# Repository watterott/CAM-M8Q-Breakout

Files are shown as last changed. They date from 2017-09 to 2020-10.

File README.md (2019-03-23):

# CAM-M8Q-Breakout
Breakout with u-blox CAM-M8Q Multi GNSS Module.

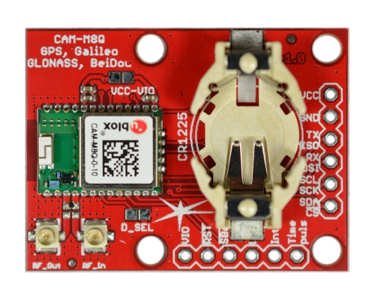
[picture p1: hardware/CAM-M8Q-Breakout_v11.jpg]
CAM-M8Q-Breakout


* [u-blox CAM-M8Q](https://www.u-blox.com/de/product/cam-m8-series) Multi GNSS Module
* GNSS Systems: GPS/QZSS, Galileo, GLONASS, BeiDou
* Interfaces: UART (default 9600 8N1), I2C/TWI (address 0x42), SPI
* on-board Antenna and optional external Antenna (u.Fl)
* 2.7 - 3.6V Power Supply
* Open-Source and released under the [Creative Commons Attribution Share-Alike License](https://creativecommons.org/licenses/by-sa/4.0/).
* **[Documentation on learn.watterott.com](https://learn.watterott.com)**

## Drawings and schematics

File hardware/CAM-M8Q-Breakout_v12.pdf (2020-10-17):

A

A

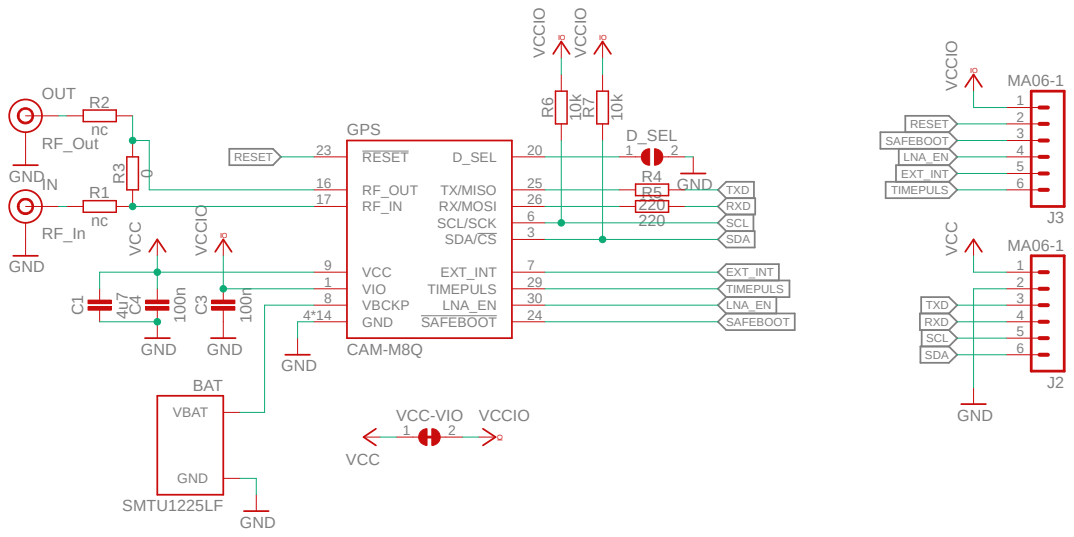
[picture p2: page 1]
GND ¹⁰⁰n; 100n VCC; GND; SMTU1225LF; MA06-1 VCCIO; VCC; VCCIO ⁴u7; ncnc; 0 RF_Out; VCCIO; 220 ¹⁰k; 10k VCCIO; Designed by Watterott electronic C⁴; VBAT; BAT; D_SEL; VCC 9 VIO 1; GND 4*14; VBCKP 8; RF_OUT 16 RF_IN 17; RESET 23; SAFEBOOT; 24 LNA_EN; EXT_INT; TX/MISO; RX/MOSI; TIMEPULS; SCL/SCK; SDA/CS; GPS; CAM-M8Q; OUT; WEEE; RoHS; RESET; LNA_EN; TXD; RXD; SCL; SDA; OSHW; Watterott

VCC-VIO C¹

Released under the Creative Commons Attribution Share-Alike
License. http://creativecommons.org/licenses/by-sa/4.0/

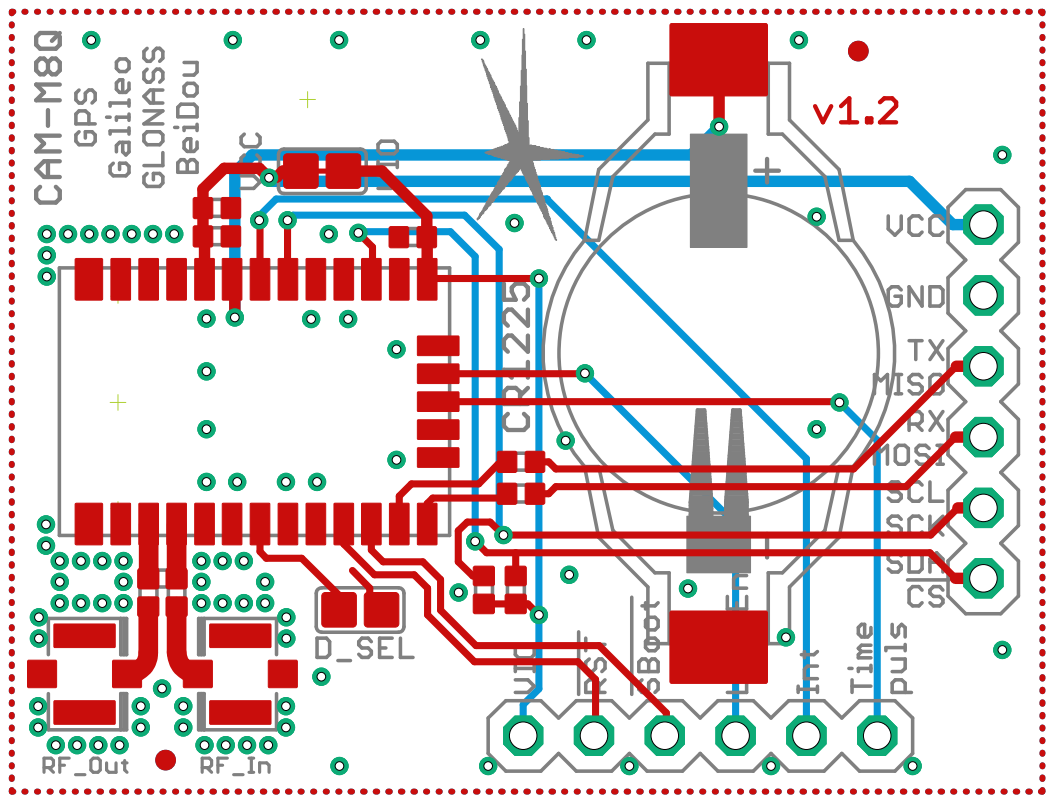
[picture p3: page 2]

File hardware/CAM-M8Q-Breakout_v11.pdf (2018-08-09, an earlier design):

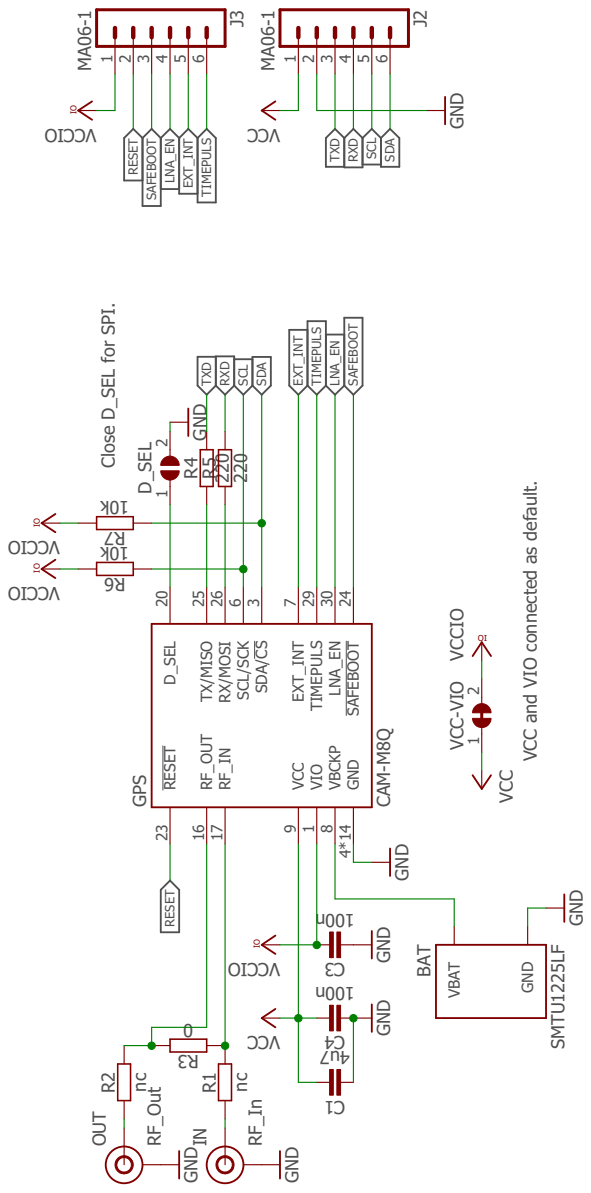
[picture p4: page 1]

Close D_SEL for SPI. VCC and VIO connected as default. GND n001 n001 CCV GND SMTU1225LF GND GND MA06-1 MA06-1 OI CCV VCC VCCIO 7u4 CCV GND GND ncnc 0 RF_Out RF_In GND GND OI CCV 220 220 k01 k01 OI CCV OI CCV Released under the Creative Commons Attribution Share-Alike License. http://creativecommons.org/licenses/by-sa/4.0/ Designed by Watterott electronic 3C4C BAT GND VBAT D_SEL2 1 J2 123456 J3 123456 VCC-VIO2 1 1C VCC 9 VIO 1 GND 4*14 VBCKP 8 RF_OUT 16 RF_IN 17 RESET 23 SAFEBOOT 24 LNA_EN 30 EXT_INT 7 TX/MISO 25 RX/MOSI 26 TIMEPULS 29 SCL/SCK 6 SDA/CS 3 GPS CAM-M8Q D_SEL 20 R1R2 3R OUT IN R4R5 6R7R Watterott OS HW RESET RESET SAFEBOOT SAFEBOOT LNA_EN LNA_EN TXD TXD RXD RXD SCL SCL SDA SDA EXT_INT EXT_INT TIMEPULS TIMEPULS ABCD 1 2 3 4 5 6 ABCD 1 2 3 4 5 6 IO OI IO IO IO

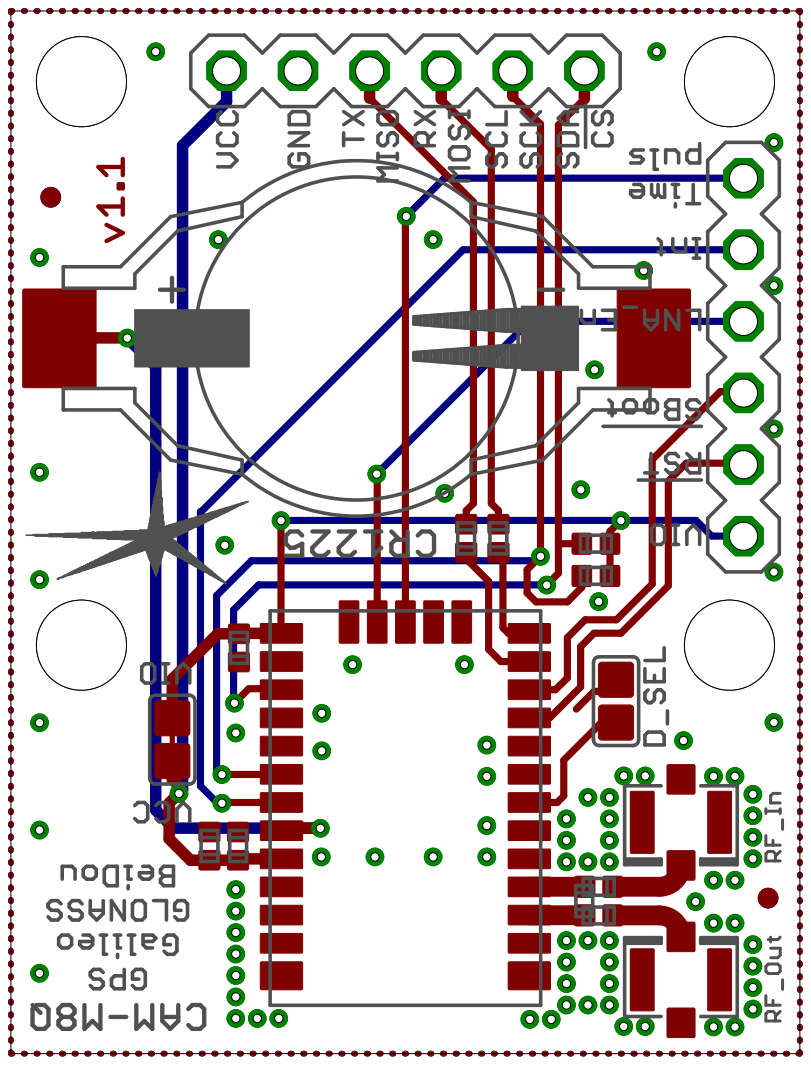
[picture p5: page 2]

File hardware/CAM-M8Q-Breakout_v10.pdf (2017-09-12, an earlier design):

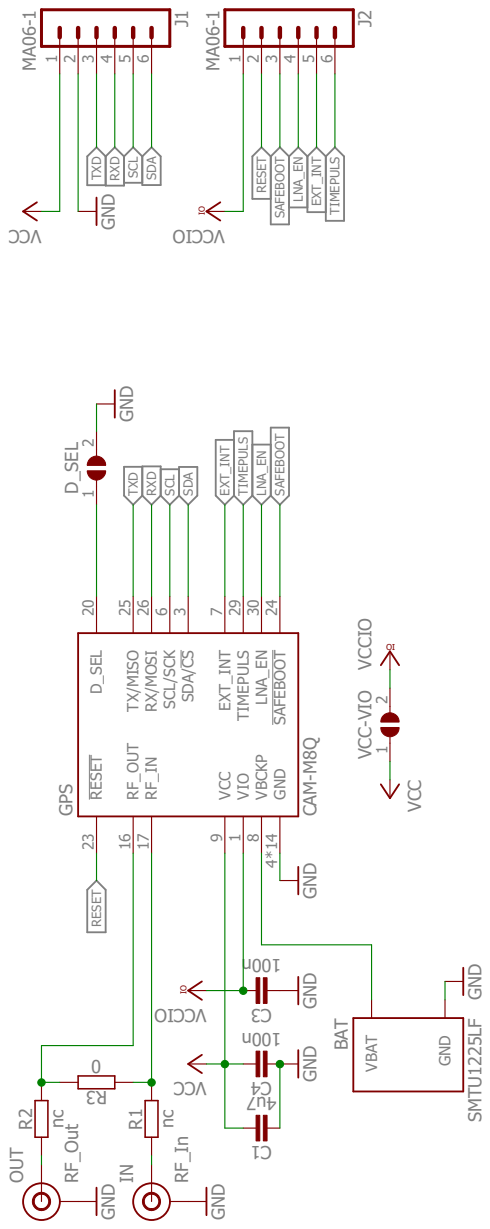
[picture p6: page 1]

GND n001 n001 CCV GND SMTU1225LF GND GND MA06-1 MA06-1 OI CCV VCC VCCIO 7u4 CCV GND GND ncnc 0 RF_Out RF_In GND GND OI CCV Released under the Creative Commons Attribution Share-Alike License. http://creativecommons.org/licenses/by-sa/4.0/ Designed by Watterott electronic 3C4C BAT GND VBAT D_SEL2 1 J1 123456 J2 123456 VCC-VIO2 1 1C VCC 9 VIO 1 GND 4*14 VBCKP 8 RF_OUT 16 RF_IN 17 RESET 23 SAFEBOOT 24 LNA_EN 30 EXT_INT 7 TX/MISO 25 RX/MOSI 26 TIMEPULS 29 SCL/SCK 6 SDA/CS 3 GPS CAM-M8Q D_SEL 20 R1R2 3R OUT IN RESET RESET SAFEBOOT SAFEBOOT LNA_EN LNA_EN TXD TXD RXD RXD SCL SCL SDA SDA EXT_INT EXT_INT TIMEPULS TIMEPULS ABCD 1 2 3 4 5 6 ABCD 1 2 3 4 5 6 OSHW IO OI IO Watterott

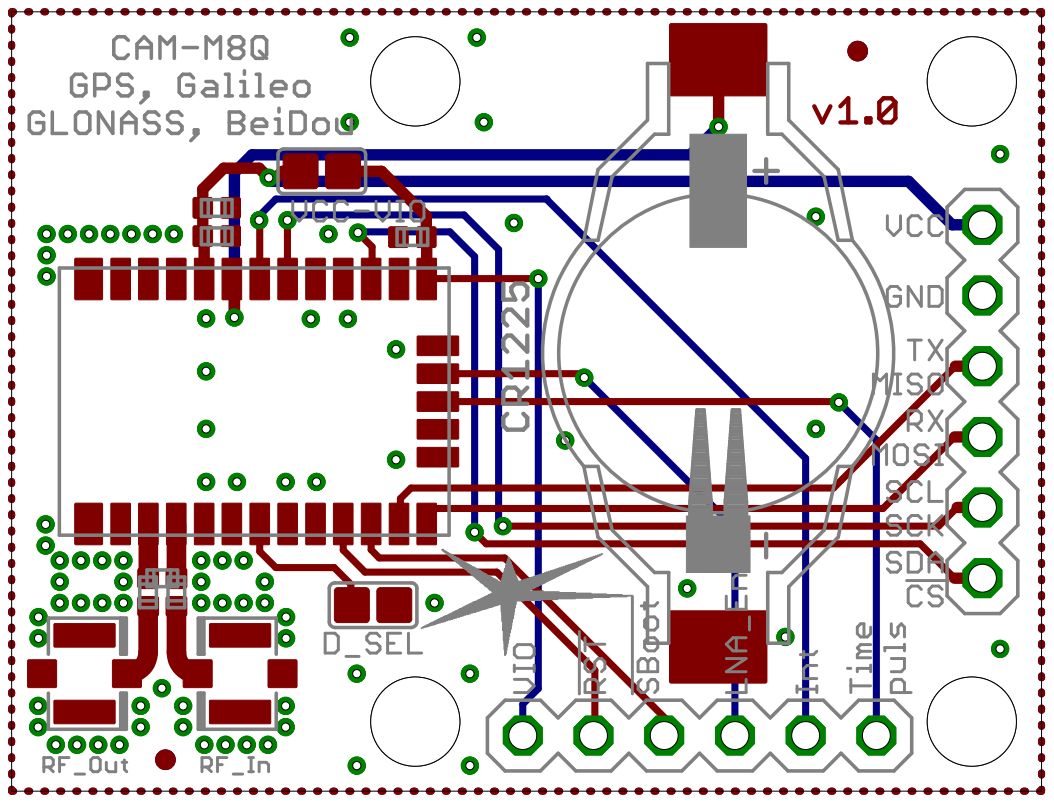
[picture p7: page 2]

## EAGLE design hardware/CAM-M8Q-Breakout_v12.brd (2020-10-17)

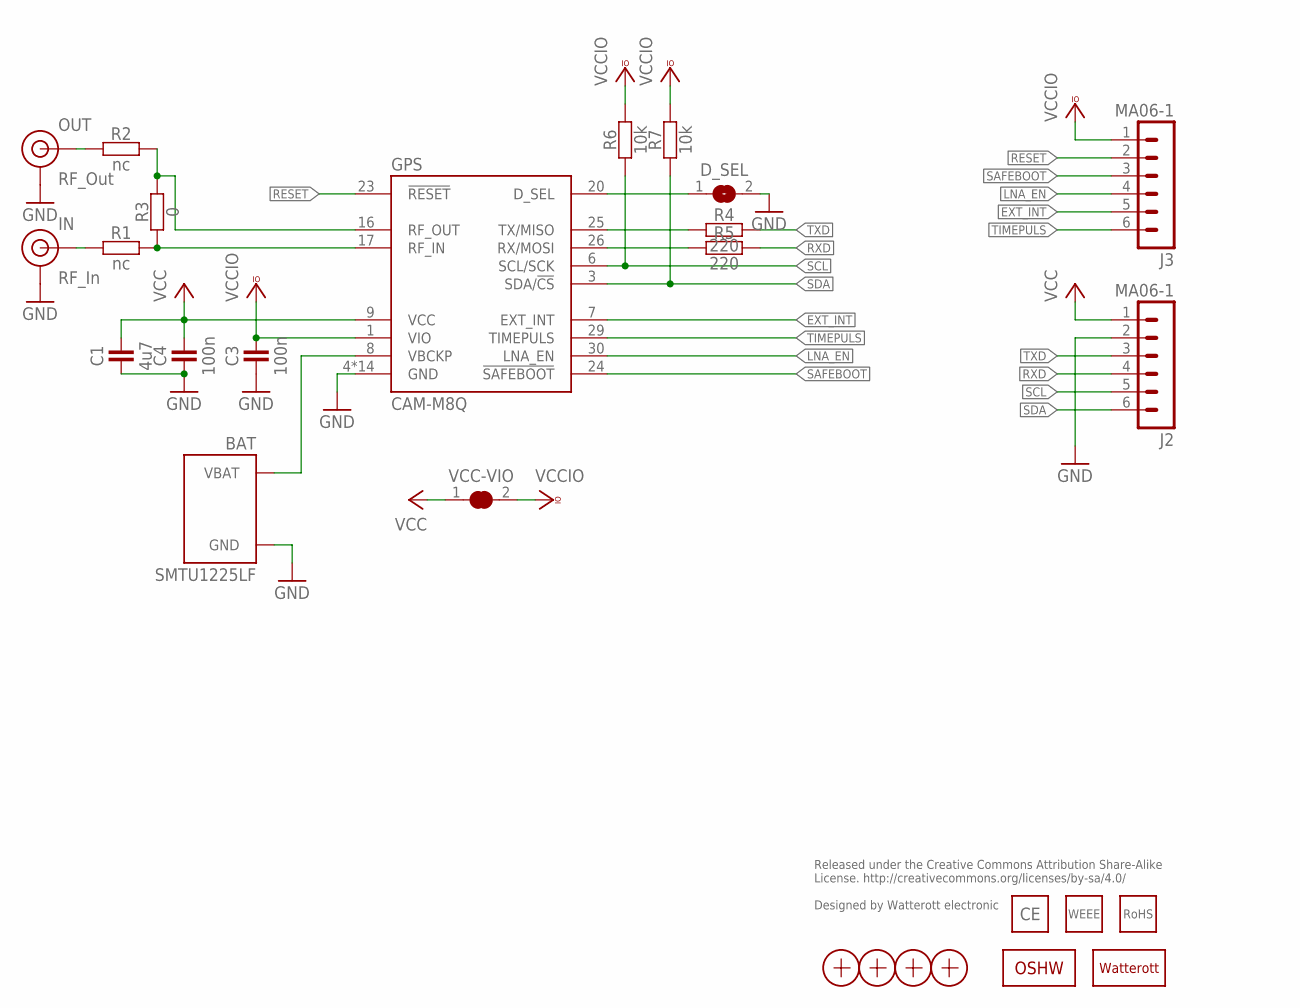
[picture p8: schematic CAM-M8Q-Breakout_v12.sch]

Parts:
BAT: SMTU1225LF; BAT-SMTU1225LF
C1: 4u7; C0402
C3, C4: 100n; C0402
D_SEL: JUMPER2-0603-NC; JUMPER2-0603_NC
GPS: CAM-M8Q
IN: RF_In; U.FL
J2, J3: MA06-1
LOGO1: LOGO-S_PLACE_M; SPARK_TPLACE_M
LOGO2: OSHW_LOGOX0070; OSHW_6X70
LOGO3: LOGO_CE-2; CE_2MM
LOGO4: LOGO_WEEE-4; WEEE_4MM
LOGO5: LOGO_ROHS-2; ROHS_2MM
OUT: RF_Out; U.FL
R1, R2: nc; C0402
R3: 0; C0402
R4, R5: 220; C0402
R6, R7: 10k; C0402
VCC-VIO: JUMPER2-0603-NC; JUMPER2-0603_NC
X1, X2, X3, X4: PASSER-07; PASSER_07MM

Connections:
D_SEL: D_SEL.1, GPS.20 (D_SEL)
EXT_INT: GPS.7 (EXT_INT), J3.5
GND: BAT.- (GND), C1.1, C3.1, C4.1, D_SEL.2, GPS.4 (GND), GPS.5 (GND), GPS.10 (GND), GPS.11 (GND), GPS.12 (GND), GPS.13 (GND), GPS.14 (GND), GPS.15 (GND), GPS.18 (GND), GPS.19 (GND), GPS.21 (GND), GPS.22 (GND), GPS.27 (GND), GPS.31 (GND), IN.1 (GND), IN.2 (GND), J2.2, OUT.1 (GND), OUT.2 (GND)
IN: IN.FEED (SIGNAL), R1.1
LNA_EN: GPS.30 (LNA_EN), J3.4
unnamed: GPS.25 (TX/MISO), R4.1
unnamed: GPS.26 (RX/MOSI), R5.1
OUT: OUT.FEED (SIGNAL), R2.1
RESET: GPS.23 (!RESET), J3.2
RFIN: GPS.17 (RF_IN), R1.2, R3.1
RFOUT: GPS.16 (RF_OUT), R2.2, R3.2
RXD: J2.4, R5.2
SAFEBOOT: GPS.24 (!SAFEBOOT), J3.3
SCL: GPS.6 (SCL/SCK), J2.5, R6.1
SDA: GPS.3 (SDA/!CS), J2.6, R7.1
TIMEPULS: GPS.29 (TIMEPULS), J3.6
TXD: J2.3, R4.2
VBCKP: BAT.+ (VBAT), GPS.8 (VBCKP)
VCC: C1.2, C4.2, GPS.9 (VCC), J2.1, VCC-VIO.1
VCCIO: C3.2, GPS.1 (VIO), J3.1, R6.2, R7.2, VCC-VIO.2

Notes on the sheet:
Released under the Creative Commons Attribution Share-Alike License. http://creativecommons.org/licenses/by-sa/4.0/ Designed by Watterott electronic

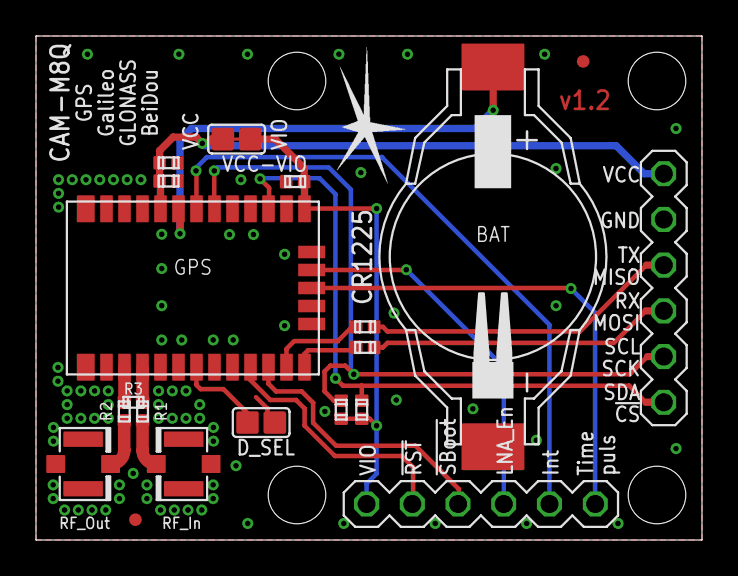
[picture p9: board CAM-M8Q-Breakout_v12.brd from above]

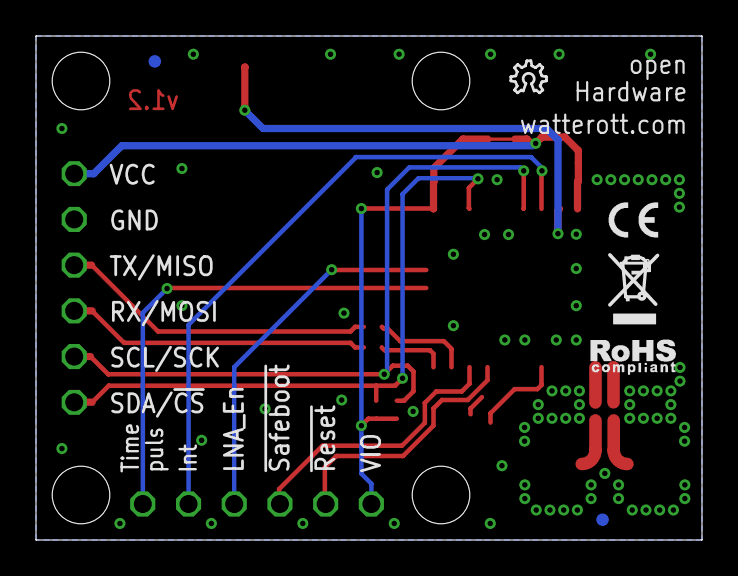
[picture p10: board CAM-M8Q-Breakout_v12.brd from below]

Board: 2 copper layers, 37.0 x 28.0 mm, 27 parts (6 on the bottom side), 20 nets.

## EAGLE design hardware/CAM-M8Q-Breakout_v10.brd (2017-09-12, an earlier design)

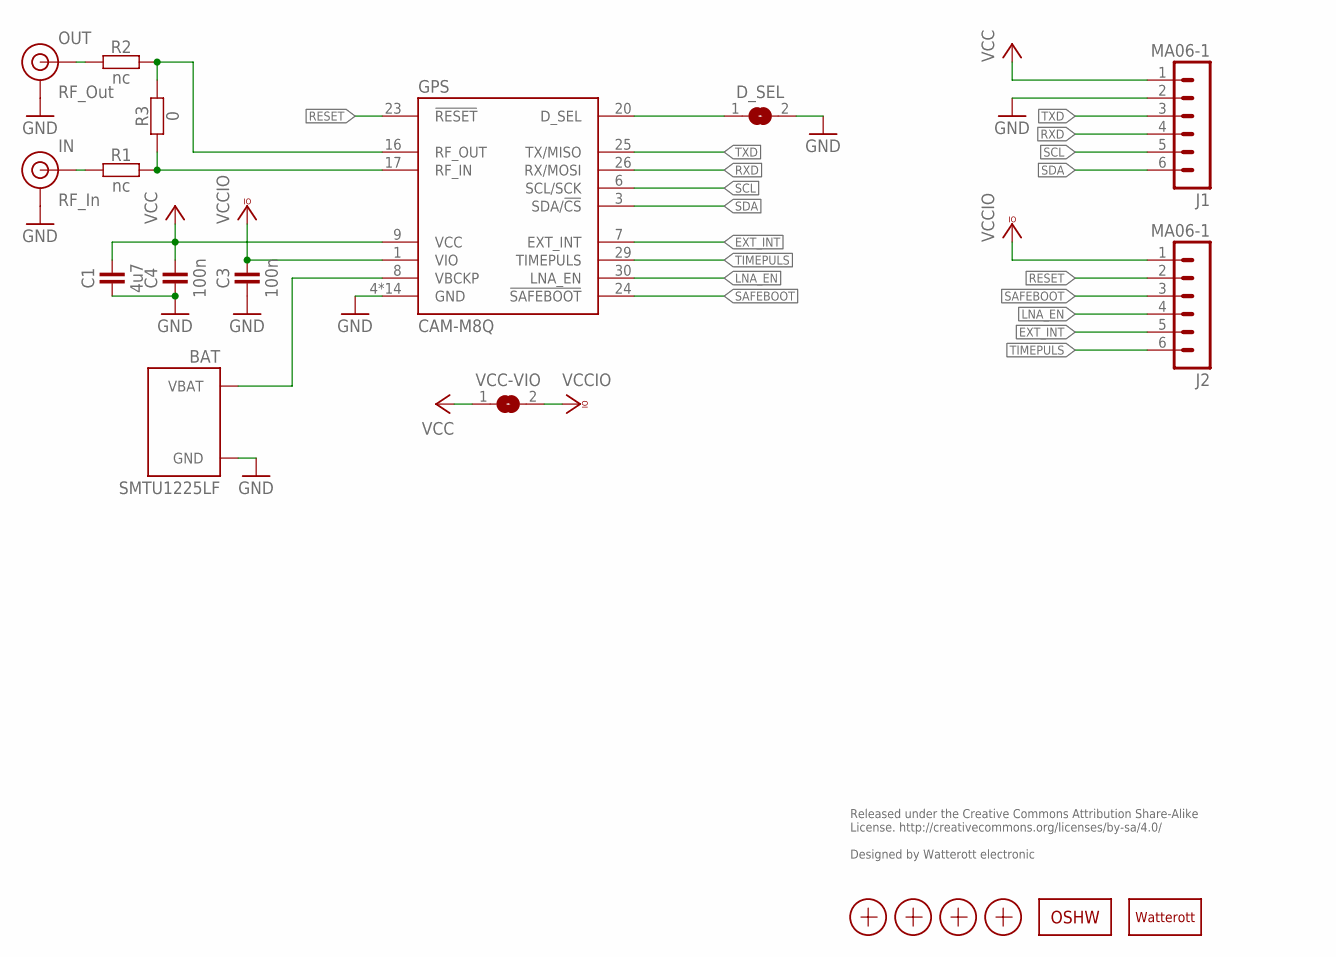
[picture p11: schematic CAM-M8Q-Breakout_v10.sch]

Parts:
BAT: SMTU1225LF; BAT-SMTU1225LF
C1: 4u7; C0402
C3, C4: 100n; C0402
D_SEL: JUMPER2-0603-NC; JUMPER2-0603_NC
GPS: CAM-M8Q
IN: RF_In; U.FL
J1, J2: MA06-1
LOGO1: LOGO-S_PLACE_M; SPARK_TPLACE_M
LOGO2: OSHW_LOGOX0070; OSHW_6X70
OUT: RF_Out; U.FL
R1, R2: nc; C0402
R3: 0; C0402
VCC-VIO: JUMPER2-0603-NC; JUMPER2-0603_NC
X1, X2, X3, X4: PASSER-07; PASSER_07MM

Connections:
D_SEL: D_SEL.1, GPS.20 (D_SEL)
EXT_INT: GPS.7 (EXT_INT), J2.5
GND: BAT.- (GND), C1.1, C3.1, C4.1, D_SEL.2, GPS.4 (GND), GPS.5 (GND), GPS.10 (GND), GPS.11 (GND), GPS.12 (GND), GPS.13 (GND), GPS.14 (GND), GPS.15 (GND), GPS.18 (GND), GPS.19 (GND), GPS.21 (GND), GPS.22 (GND), GPS.27 (GND), GPS.31 (GND), IN.1 (GND), IN.2 (GND), J1.2, OUT.1 (GND), OUT.2 (GND)
IN: IN.FEED (SIGNAL), R1.1
LNA_EN: GPS.30 (LNA_EN), J2.4
OUT: OUT.FEED (SIGNAL), R2.1
RESET: GPS.23 (!RESET), J2.2
RFIN: GPS.17 (RF_IN), R1.2, R3.1
RFOUT: GPS.16 (RF_OUT), R2.2, R3.2
RXD: GPS.26 (RX/MOSI), J1.4
SAFEBOOT: GPS.24 (!SAFEBOOT), J2.3
SCL: GPS.6 (SCL/SCK), J1.5
SDA: GPS.3 (SDA/!CS), J1.6
TIMEPULS: GPS.29 (TIMEPULS), J2.6
TXD: GPS.25 (TX/MISO), J1.3
VBCKP: BAT.+ (VBAT), GPS.8 (VBCKP)
VCC: C1.2, C4.2, GPS.9 (VCC), J1.1, VCC-VIO.1
VIO: C3.2, GPS.1 (VIO), J2.1, VCC-VIO.2

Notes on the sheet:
Released under the Creative Commons Attribution Share-Alike License. http://creativecommons.org/licenses/by-sa/4.0/ Designed by Watterott electronic

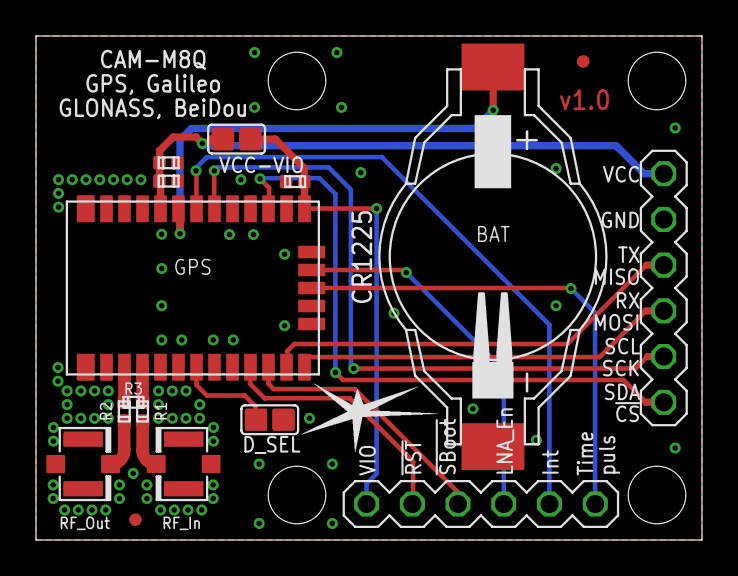
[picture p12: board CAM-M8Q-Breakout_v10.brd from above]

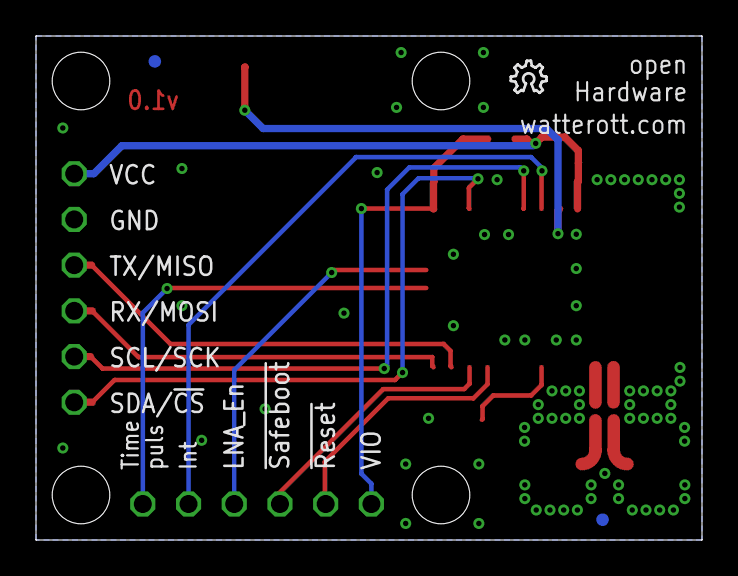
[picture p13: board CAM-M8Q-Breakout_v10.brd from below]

Board: 2 copper layers, 37.0 x 28.0 mm, 20 parts (3 on the bottom side), 18 nets.

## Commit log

2017-09-12 updated layout and schematics
    [CAM-M8Q-Breakout_v10.brd, CAM-M8Q-Breakout_v10.sch]
2018-05-01 added rev 1.1
    [CAM-M8Q-Breakout_v11.brd, CAM-M8Q-Breakout_v11.sch]
2018-08-09 updated schematics
    [CAM-M8Q-Breakout_v10.sch, CAM-M8Q-Breakout_v11.sch]
2020-10-17 added V1.2
    [CAM-M8Q-Breakout_v12.brd, CAM-M8Q-Breakout_v12.sch]
